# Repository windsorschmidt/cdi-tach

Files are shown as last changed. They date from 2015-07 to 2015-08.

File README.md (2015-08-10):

# CDI Tachometer

Microcontroller circuit and firmware to read the tachometer signal from a motorcycle CDI module (tested on a 1990 Suzuki DR350S).

The output signal is a ground-referenced pulse of about 40V following each ignition event at a frequency of 1 per two crank revolutions. e.g. a pulse frequency of 60Hz yields 7200RPM.

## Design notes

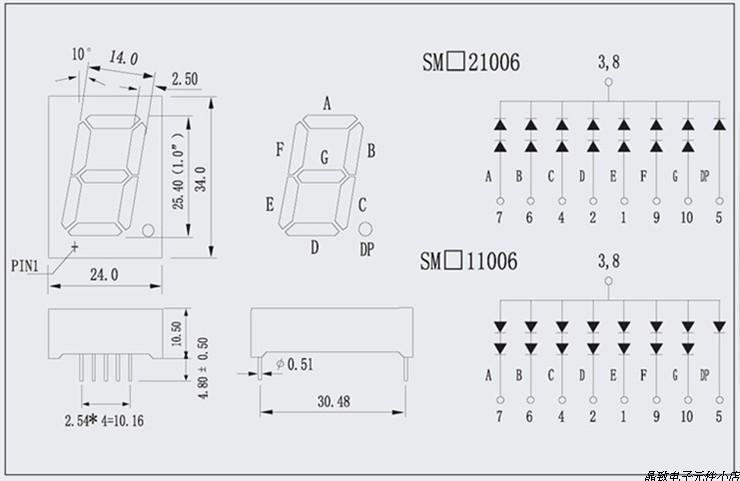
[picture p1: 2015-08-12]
datasheets/7-segment-LED.jpg

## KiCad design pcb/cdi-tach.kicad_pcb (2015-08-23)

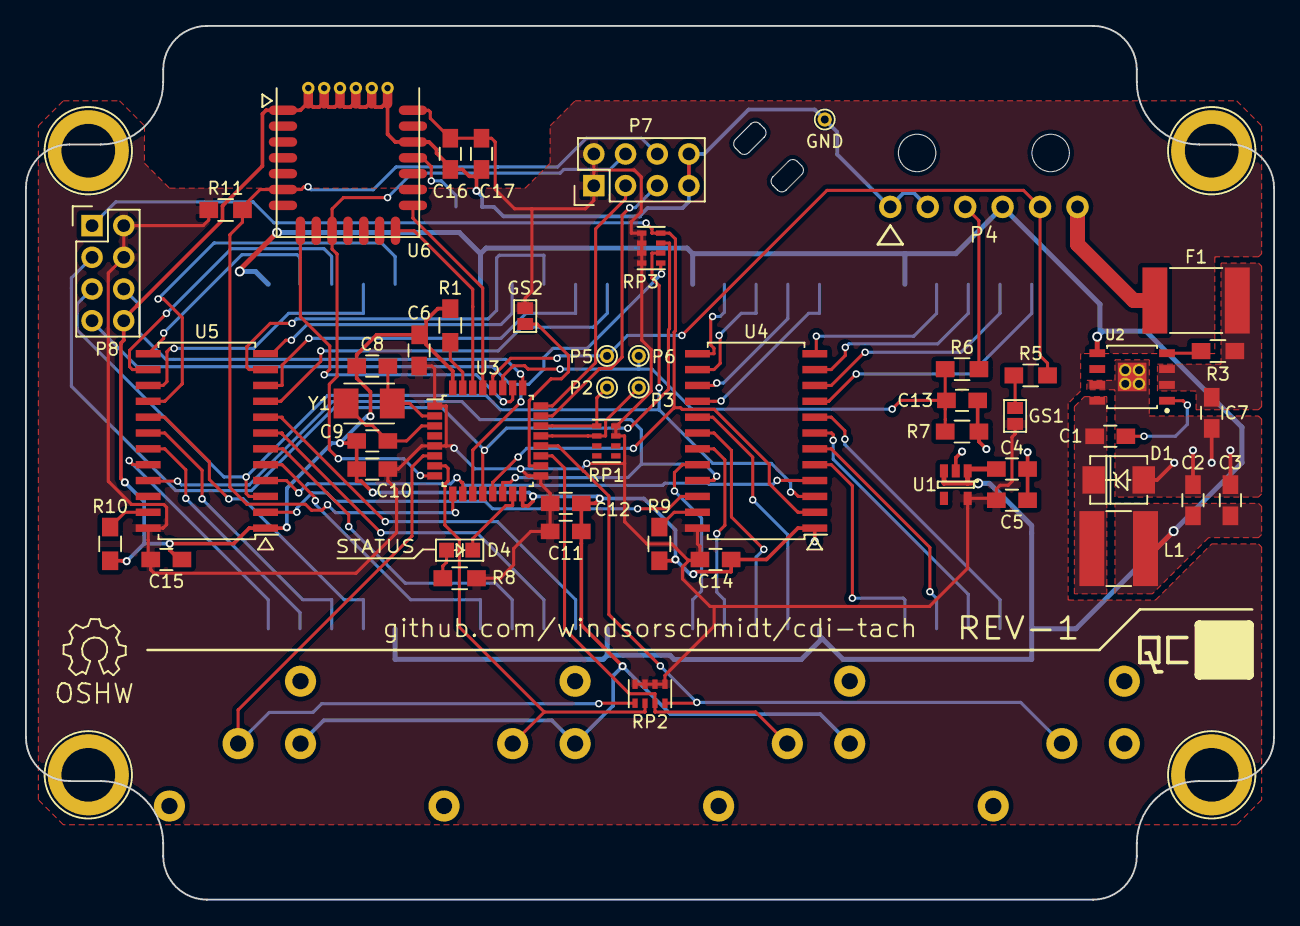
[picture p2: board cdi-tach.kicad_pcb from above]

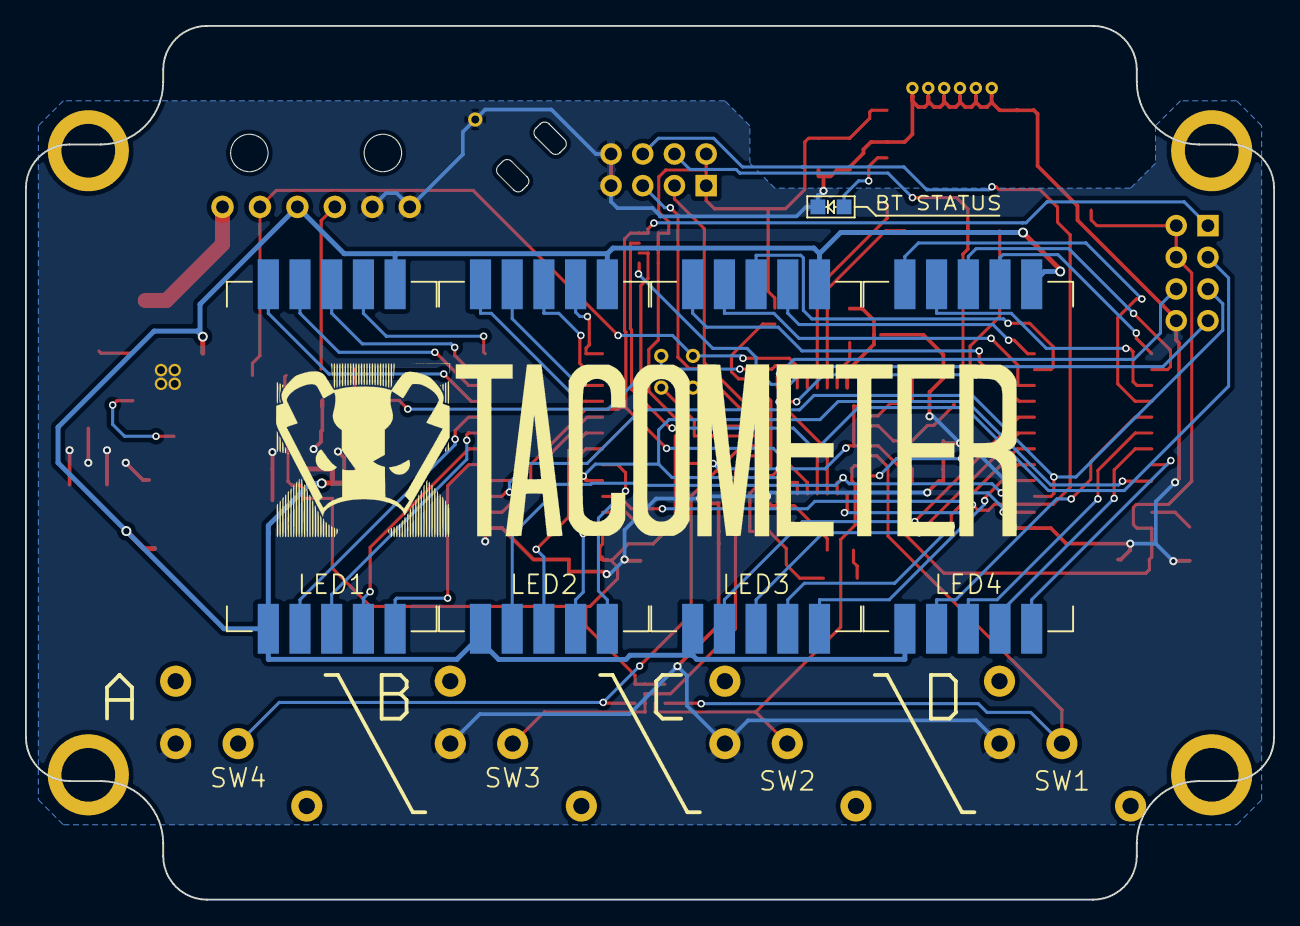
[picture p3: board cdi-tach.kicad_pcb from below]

Board: 2 copper layers, 100.0 x 70.0 mm, 70 parts (11 on the bottom side), 74 nets.

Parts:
ART1: badger_logo; badger_face_logo
ART2: OSHW_logo; Symbol_OSHW-Logo_SilkScreen
ART3: part_logo; tacometer_logo
ART4: QC_label; label_qc
C1, C6, C10, C12, C17: 100nF; C_0805_HandSoldering
C2, C3: 22uF; C_0805_HandSoldering
C4, C5, C14, C15: 1uF; C_0805_HandSoldering
C7, C16: 10uF; C_0805_HandSoldering
C8, C9: 18pF; C_0805_HandSoldering
C11: 4.7uF; C_0805_HandSoldering
C13: 22nF; C_0805_HandSoldering
D1: SSB44; Diode_SSB44
D4: STATUS; LED_0805
D5: BT STATUS; LED_0805
F1: 3.7A Polyswitch; Fuse_Resettable
GND: GND; PINTST
GS1: SPD_PU; GS2
GS2: MODE; GS2
L1: 6.8uH; Inductor_Bourns_SRN6045_6mm
LED1, LED2, LED3, LED4: ACSA08-51SEKWA
MNT1, MNT6: zip_tie_slot; MOUNT_ZIP_TIE
MNT2, MNT3, MNT4, MNT5: 4mm_screw; Screw_M4
P2: SDA; PINTST
P3: SCL; PINTST
P4: PWR_SPD_TACH; micro-fit_1x6_ra
P5: SPEED; PINTST
P6: TACH; PINTST
P7: DEBUG; Pin_Header_Straight_2x04
P8: LCD; Pin_Header_Straight_2x04
PCB enclosure: PCB_enclosure; pcb_enclosure
R1, R5, R9, R10: 3K; R_0805_HandSoldering
R3, R6: 100K; R_0805_HandSoldering
R7: 12.1K; R_0805_HandSoldering
R8: 39; R_0805_HandSoldering
R11: 10K; R_0805_HandSoldering
RP1, RP2, RP3: 4.7K; R_Cat16-4
SW1: A; pushbutton_marquardt_6450
SW2: B; pushbutton_marquardt_6450
SW3: C; pushbutton_marquardt_6450
SW4: D; pushbutton_marquardt_6450
U1: MIC5504-3.3YM5; SOT-23-5
U2: ADP2302ARDZ-5.0; ADP2302_SOIC8
U3: STM32F030K6T6; LQFP-32_7x7mm_Pitch0.8mm
U4, U5: CAT4016; SOIC-24_7.5x15.4mm_Pitch1.27mm
U6: AMS002-S
Y1: 7A-8.000MAAE-T; crystal_txc_7a_5x3.2mm

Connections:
+3V3: C5.1, C6.2, C10.2, C11.1, C12.1, C14.2, C15.2, C16.1, C17.1, GS1.2, GS2.2, P7.1, P7.2, P8.2, P8.4, R8.2, R11.1, RP1.7, RP1.8, RP2.5, RP2.6, RP2.7, RP2.8, RP3.1, RP3.2, RP3.3, RP3.4, U1.5, U3.1, U3.5, U3.17, U4.24, U5.24, U6.21
+5V: C2.1, C3.1, C4.1, L1.2, LED1.1, LED1.6, LED2.1, LED2.6, LED3.1, LED3.6, LED4.1, LED4.6, P4.3, U1.1, U1.3, U2.5
+12V: F1.1, P4.1
BTN_A: RP2.1, SW1.1, U3.6
BTN_B: RP2.2, SW2.1, U3.7
BTN_C: RP2.3, SW3.1, U3.19
BTN_D: RP2.4, SW4.1, U3.20
BT_CONN: U3.29, U6.15
BT_NRST: U3.26, U6.8
BT_STRM: U3.30, U6.14
GND: C2.2, C3.2, C4.2, C5.2, C6.1, C7.1, C8.1, C9.1, C10.1, C11.2, C12.2, C13.1, C14.1, C15.1, C16.2, C17.2, D1.1, D5.1, GND.1, P4.5, P4.6, P7.7, P7.8, P8.8, R1.2, R7.2, R9.2, R10.2, SW1.2, SW2.2, SW3.2, SW4.2, U1.2, U2.7, U2.9, U3.16, U3.32, U4.1, U5.1, U6.1, U6.19, U6.22, U6.23, U6.24, U6.25, U6.26, U6.27
LCD_RST: P8.6, U3.25
LED1_A: LED1.8, U4.11
LED1_B: LED1.7, U4.12
LED1_C: LED1.4, U4.6
LED1_D: LED1.3, U4.7
LED1_DP: LED1.5, U4.5
LED1_E: LED1.2, U4.8
LED1_F: LED1.9, U4.10
LED1_G: LED1.10, U4.9
LED2_A: LED2.8, U4.14
LED2_B: LED2.7, U4.13
LED2_C: LED2.4, U4.19
LED2_D: LED2.3, U4.18
LED2_DP: LED2.5, U4.20
LED2_E: LED2.2, U4.17
LED2_F: LED2.9, U4.15
LED2_G: LED2.10, U4.16
LED3_A: LED3.8, U5.11
LED3_B: LED3.7, U5.12
LED3_C: LED3.4, U5.6
LED3_D: LED3.3, U5.7
LED3_DP: LED3.5, U5.5
LED3_E: LED3.2, U5.8
LED3_F: LED3.9, U5.10
LED3_G: LED3.10, U5.9
LED4_A: LED4.8, U5.14
LED4_B: LED4.7, U5.13
LED4_C: LED4.4, U5.19
LED4_D: LED4.3, U5.18
LED4_DP: LED4.5, U5.20
LED4_E: LED4.2, U5.17
LED4_F: LED4.9, U5.15
LED4_G: LED4.10, U5.16
LED_BLANK: U3.14, U4.21, U5.21
LED_LATCH: U3.10, U4.4, U5.4
unnamed: C1.1, D1.2, L1.1, U2.8
unnamed: C1.2, U2.1
unnamed: C7.2, F1.2, R3.2, U2.2, U2.3
unnamed: C8.2, U3.2, Y1.2
unnamed: C9.2, U3.3, Y1.1
unnamed: D4.1, U3.15
unnamed: D4.2, R8.1
unnamed: D5.2, U6.18
unnamed: GS1.1, R5.2
unnamed: GS2.1, U3.18
unnamed: P2.1, RP1.1, U3.22
unnamed: P3.1, RP1.2, U3.21
unnamed: P4.4, R6.1
unnamed: R1.1, U3.31
unnamed: R3.1, U2.4
unnamed: R9.1, U4.23
unnamed: R10.1, U5.23
unnamed: U4.22, U5.2
SPEED: P4.2, P5.1, R5.1, U3.28
SPI_CS: P8.7, RP3.5, U3.11
SPI_MISO: P8.3, RP3.7, U3.12
SPI_MOSI: P8.1, RP3.8, U3.13, U4.2
SPI_SCK: P8.5, RP3.6, U4.3, U5.3
SWCLK: P7.3, U3.24
SWDIO: P7.5, U3.23
TACH: C13.2, P6.1, R6.2, R7.1, U3.27
USART_RX: P7.6, R11.2, U3.9, U6.6
USART_TX: P7.4, U3.8, U6.10

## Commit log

2015-07-30 added annotation
    [cdi-tach.sch]
2015-08-03 misc edits
    [cdi-tach.sch]
2015-08-03 building out schematic
    [cdi-tach.sch]
2015-08-10 schematic updates
    [cdi-tach.sch]
2015-08-11 adding discrete LEDs
    [cdi-tach.sch, discrete_leds.sch]
2015-08-12 added input filter schematic for spice simulation
    [tach_pulse_filter.kicad_pcb, tach_pulse_filter.sch]
2015-08-12 updated schematic
    [cdi-tach.sch, discrete_leds.sch]
2015-08-12 added footprints
2015-08-12 schematic updates. added footprint association. added schematic sheet for PCB artwork and miscellaneous features
    [cdi-tach.sch, discrete_leds.sch, misc.sch]
2015-08-13 added footprints for artwork
2015-08-13 started pcb layout
    [cdi-tach.kicad_pcb, misc.sch]
2015-08-13 pcb layout
    [cdi-tach.kicad_pcb]
2015-08-15 removed discrete LEDs (probably not enough room). remapped segments to LED drivers for easier routing
    [cdi-tach.kicad_pcb, cdi-tach.sch, discrete_leds.sch]
2015-08-15 tweaking design rules for autorouter
    [cdi-tach.kicad_pcb]
2015-08-16 added autorouter files
    [cdi-tach.dsn]
2015-08-17 added gerber and drill files
    [cdi-tach-B_Cu.gbr, cdi-tach-B_Mask.gbr, cdi-tach-B_SilkS.gbr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]
2015-08-17 moved fabrication files to subdirectory
    [cdi-tach-B_Cu.gbr, cdi-tach-B_Mask.gbr, cdi-tach-B_SilkS.gbr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]
2015-08-17 added datasheets for bluetooth module and surface-mound led displays
    [cdi-tach.kicad_pcb]
2015-08-22 hopefully finished trace routing. passes DRC
    [cdi-tach.kicad_pcb]
2015-08-22 adjusted silkscreen references
    [cdi-tach.kicad_pcb]
2015-08-22 removed gerber files; they can be generated from the kicad pcb file whenever
    [cdi-tach-B_Cu.gbr, cdi-tach-B_Mask.gbr, cdi-tach-B_SilkS.gbr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]
2015-08-22 tweaking vias and silkscreen to avoid overlaps
    [cdi-tach.kicad_pcb]
2015-08-23 resizing PCB for enclosure
    [cdi-tach.kicad_pcb]

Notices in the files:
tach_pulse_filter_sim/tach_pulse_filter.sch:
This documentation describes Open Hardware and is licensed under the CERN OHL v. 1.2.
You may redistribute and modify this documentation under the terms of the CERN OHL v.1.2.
